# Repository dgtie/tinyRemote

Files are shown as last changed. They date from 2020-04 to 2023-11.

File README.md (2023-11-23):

# This project is obsolete
- please click [new tiny IR remote](https://github.com/dgtie/tinyRemote1/tree/main)

# tinyRemote
An infrared remote control with attiny414\
powered by 2 x AAA
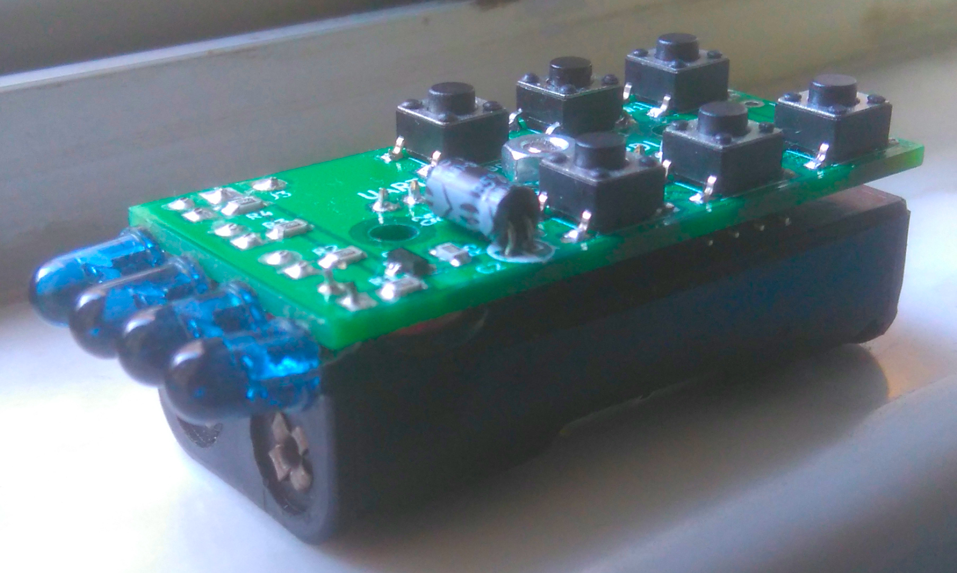
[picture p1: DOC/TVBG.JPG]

## Keys
```
              ____
vol- (99)    |o  o| ch-  (77)
vol+ (32)    |o  o| ch+  (31)
shift(power) |o  o| input(mute)
             |____|
              UUUU

Hit SHIFT and indicator will turn on. Then hit a button while indicator is on.

It shall work for SHARP, LG and TOSHIBA.
It shall also work for SONY, PHILIPS and SAMSUNG. (but not yet verified)
```
## Connecting to PC
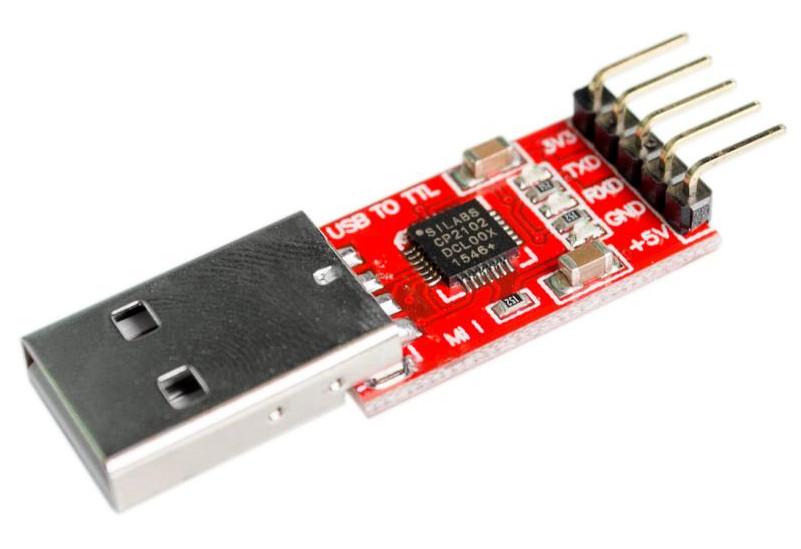
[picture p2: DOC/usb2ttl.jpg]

```
              ____
             |o  o| GND
      [UART] |o  o| 3V3
         GND |o  o| [UPDI]
         3V3 |____|
              UUUU
```
Connect tinyRemote to PC using a USB2TTL module via UPDI port or UART port. UPDI port is for programming attiny414. I am using [pyupdi](https://github.com/mraardvark/pyupdi).\
UART port is used for reading infrared code. There is an infrared transistor near the LED indicator. Point your remote controller CLOSE to it. To enter reading mode:
1. remove batteries
2. power up tinyRemote via UART port
3. IF SUCCESS, indicator will turn on. (It is a minor bug! Upon startup, Rx pin is checked. If it is high, enter reading mode.)

Baud rate is 115200. PC will receive BINARIES from tinyRemote representing the durations of marks and spaces. ZERO means break. The timing unit is 4.8 us.\
b2str.cpp is to convert the binaries to readable text string. The output will be durations in us.\
Decoding is done by PC (decode.cpp)\
pronto.cpp converts pronto hex to durations stream that to be decoded by decode.cpp
## Schematic
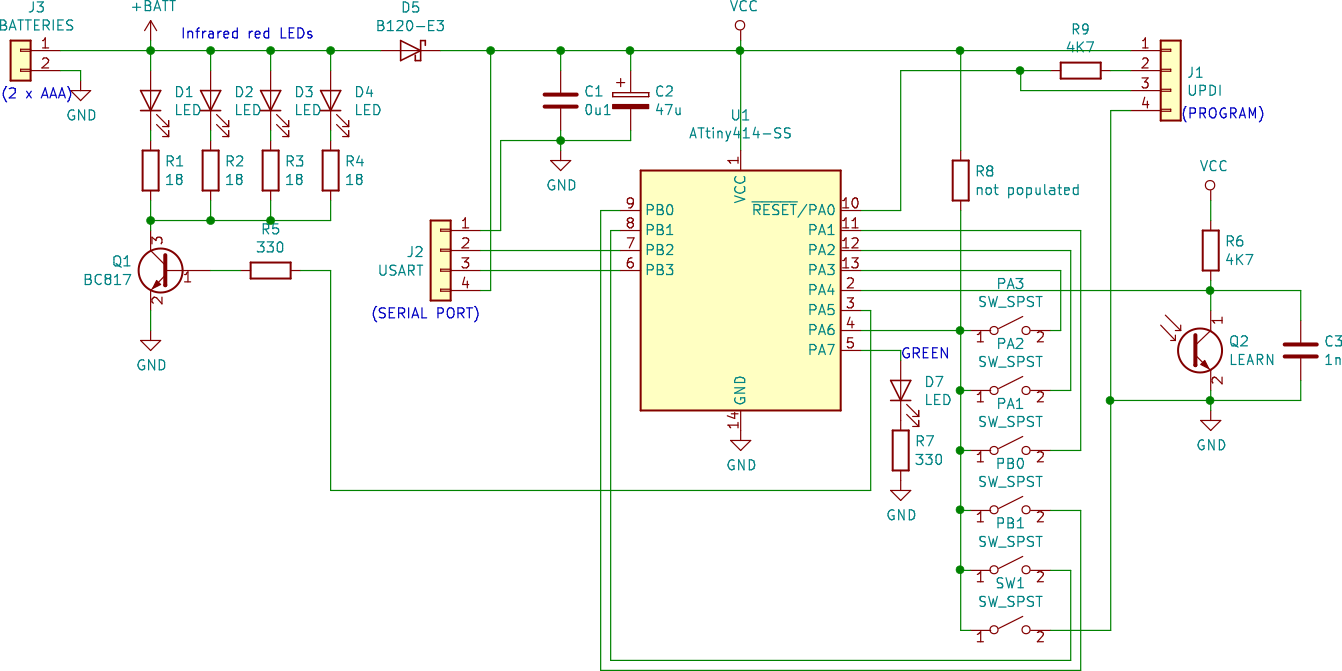
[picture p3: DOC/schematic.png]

https://user-images.githubusercontent.com/42087847/192790861-0ea7e591-97eb-486d-b9d1-ebd6bcc5e6a8.mp4

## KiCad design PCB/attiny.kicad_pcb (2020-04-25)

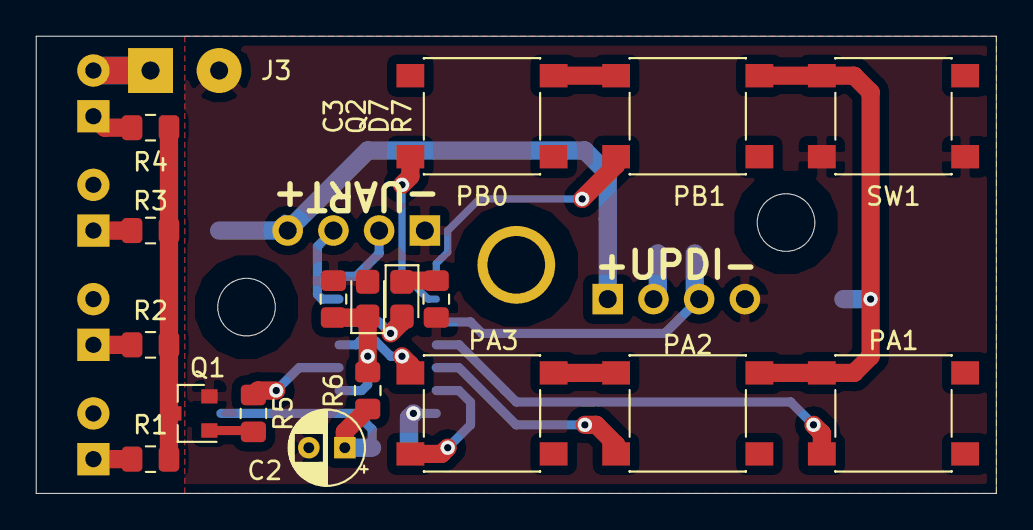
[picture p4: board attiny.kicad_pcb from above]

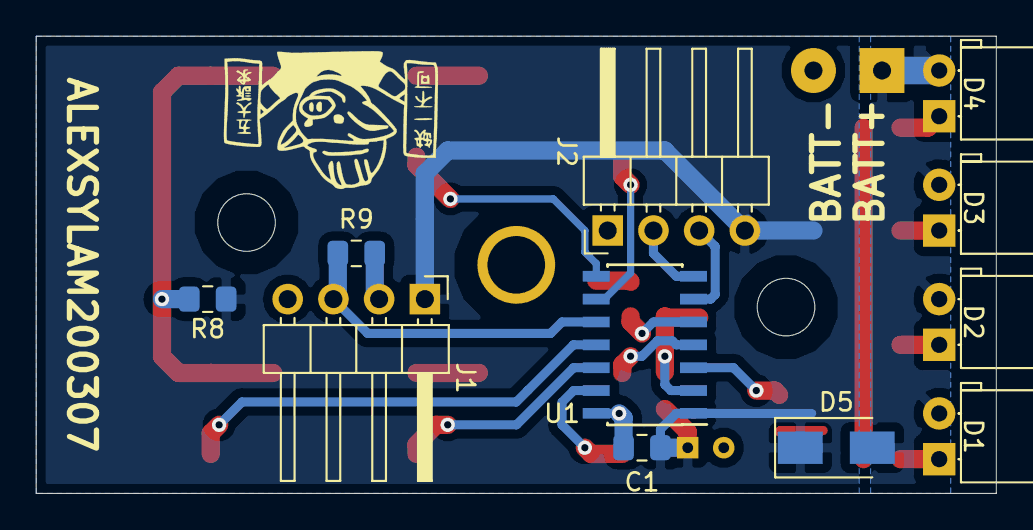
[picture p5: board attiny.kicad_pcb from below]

Board: 2 copper layers, 53.3 x 25.4 mm, 30 parts (11 on the bottom side), 23 nets.

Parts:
C1: 0u1; C_0805_2012Metric_Pad1.15x1.40mm_HandSolder
C2: 47u; CP_Radial_D4.0mm_P2.00mm
C3: 1n; C_0805_2012Metric_Pad1.15x1.40mm_HandSolder
D1, D2, D3, D4: LED; LED_D5.0mm_Horizontal_O1.27mm_Z3.0mm
D5: B120-E3; D_SMA
D7: LED; LED_0805_2012Metric_Castellated
J1, J2: Conn_01x04; PinHeader_1x04_P2.54mm_Horizontal
J3: Conn_01x02; SolderWirePad_1x02_P3.81mm_Drill1mm
PA1, PA2, PA3: SW_SPST; SW_SPST_PTS645
PB0, PB1: SW_SPST; SW_SPST_PTS645
Q1: BC817; SOT-23
Q2: Q_Photo_NPN; LED_0805_2012Metric_Castellated
R1, R2, R3, R4: 18; R_0805_2012Metric_Pad1.15x1.40mm_HandSolder
R5, R6, R8, R9: 4K7; R_0805_2012Metric_Pad1.15x1.40mm_HandSolder
R7: 330; R_0805_2012Metric_Pad1.15x1.40mm_HandSolder
SW1: SW_SPST; SW_SPST_PTS645
U1: ATtiny814-SS; SOIC-14_3.9x8.7mm_P1.27mm

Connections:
+BATT: D1.2, D2.2, D3.2, D4.2, D5.2, J3.1
GND: C1.2, C2.2, C3.2, J1.4, J2.1, J3.2, Q1.2, Q2.2, R7.2, SW1.2, U1.14
unnamed: C3.1, Q2.1, R6.2, U1.2
unnamed: D1.1, R1.1
unnamed: D2.1, R2.1
unnamed: D3.1, R3.1
unnamed: D4.1, R4.1
unnamed: D7.1, R7.1
unnamed: D7.2, U1.5
unnamed: J1.2, R9.1
unnamed: J1.3, R9.2, U1.10
unnamed: J2.2, U1.7
unnamed: J2.3, U1.6
unnamed: PA1.1, PA2.1, PA3.1, PB0.1, PB1.1, R8.2, SW1.1, U1.4
unnamed: PA1.2, U1.11
unnamed: PA2.2, U1.12
unnamed: PA3.2, U1.13
unnamed: PB0.2, U1.9
unnamed: PB1.2, U1.8
unnamed: Q1.1, R5.2
unnamed: Q1.3, R1.2, R2.2, R3.2, R4.2
unnamed: R5.1, U1.3
VCC: C1.1, C2.1, D5.1, J1.1, J2.4, R6.1, R8.1, U1.1

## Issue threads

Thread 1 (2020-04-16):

Instructions for compiling

alejomongua, 2020-04-16:
Hello.

I think this is a very interesting project. I am particularly interested in compiling and programing attiny414 on Linux.

I cloned your project, chaged the BIN variable in makefile for /usr/bin (which is where avr-* executables are located) but Im not able to compile.

I have avr-g++ versión 9.3.0 and I'm using manjaro

I have the following output when i run `make`

    /usr/bin/avr-g++ -mmcu=attiny414 -Os -o main.o -c main.cpp
    In file included from /usr/avr/include/avr/interrupt.h:38,
                     from main.cpp:1:
    /usr/avr/include/avr/io.h:581:6: warning: #warning "device type not defined" [-Wcpp]
      581 | #    warning "device type not defined"
          |      ^~~~~~~
    main.cpp: In function 'void init()':
    main.cpp:31:3: error: 'PORTA' was not declared in this scope; did you mean 'PORT0'?
       31 |   PORTA.DIRSET = PIN7_bm | PIN5_bm | PIN3_bm | PIN2_bm | PIN1_bm;
          |   ^~~~~
          |   PORT0
    main.cpp:31:18: error: 'PIN7_bm' was not declared in this scope; did you mean 'PIN7'?
       31 |   PORTA.DIRSET = PIN7_bm | PIN5_bm | PIN3_bm | PIN2_bm | PIN1_bm;
          |                  ^~~~~~~
          |                  PIN7
    main.cpp:31:28: error: 'PIN5_bm' was not declared in this scope; did you mean 'PIN5'?
       31 |   PORTA.DIRSET = PIN7_bm | PIN5_bm | PIN3_bm | PIN2_bm | PIN1_bm;
          |                            ^~~~~~~
          |                            PIN5
    main.cpp:31:38: error: 'PIN3_bm' was not declared in this scope; did you mean 'PIN3'?
       31 |   PORTA.DIRSET = PIN7_bm | PIN5_bm | PIN3_bm | PIN2_bm | PIN1_bm;
          |                                      ^~~~~~~
          |                                      PIN3
    main.cpp:31:48: error: 'PIN2_bm' was not declared in this scope; did you mean 'PIN2'?
       31 |   PORTA.DIRSET = PIN7_bm | PIN5_bm | PIN3_bm | PIN2_bm | PIN1_bm;
          |                                                ^~~~~~~
          |                                                PIN2
    main.cpp:31:58: error: 'PIN1_bm' was not declared in this scope; did you mean 'PIN1'?
       31 |   PORTA.DIRSET = PIN7_bm | PIN5_bm | PIN3_bm | PIN2_bm | PIN1_bm;
          |                                                          ^~~~~~~
          |                                                          PIN1
    main.cpp:32:3: error: 'PORTB' was not declared in this scope; did you mean 'PORT0'?
       32 |   PORTB.DIRSET = PIN2_bm | PIN1_bm | PIN0_bm;
          |   ^~~~~
          |   PORT0
    main.cpp:32:38: error: 'PIN0_bm' was not declared in this scope; did you mean 'PIN0'?
       32 |   PORTB.DIRSET = PIN2_bm | PIN1_bm | PIN0_bm;
          |                                      ^~~~~~~
          |                                      PIN0
    main.cpp:33:3: error: 'TCB0' was not declared in this scope
       33 |   TCB0.CTRLB = TCB_CCMPEN_bm | TCB_CNTMODE_PWM8_gc; // carrier
          |   ^~~~
    main.cpp:33:16: error: 'TCB_CCMPEN_bm' was not declared in this scope
       33 |   TCB0.CTRLB = TCB_CCMPEN_bm | TCB_CNTMODE_PWM8_gc; // carrier
          |                ^~~~~~~~~~~~~
    main.cpp:33:32: error: 'TCB_CNTMODE_PWM8_gc' was not declared in this scope
       33 |   TCB0.CTRLB = TCB_CCMPEN_bm | TCB_CNTMODE_PWM8_gc; // carrier
          |                                ^~~~~~~~~~~~~~~~~~~
    main.cpp:34:3: error: 'TCA0' was not declared in this scope
       34 |   TCA0.SINGLE.INTCTRL = TCA_SINGLE_OVF_bm;
          |   ^~~~
    main.cpp:34:25: error: 'TCA_SINGLE_OVF_bm' was not declared in this scope
       34 |   TCA0.SINGLE.INTCTRL = TCA_SINGLE_OVF_bm;
          |                         ^~~~~~~~~~~~~~~~~
    main.cpp: In lambda function:
    main.cpp:46:7: error: 'USART0' was not declared in this scope
       46 |   if (USART0.CTRLB) usart0(count);
          |       ^~~~~~
    main.cpp:49:5: error: 'TCA0' was not declared in this scope
       49 |     TCA0.SINGLE.CTRLA = TCA_SINGLE_CLKSEL_DIV1_gc | TCA_SINGLE_ENABLE_bm;
          |     ^~~~
    main.cpp:49:25: error: 'TCA_SINGLE_CLKSEL_DIV1_gc' was not declared in this scope
       49 |     TCA0.SINGLE.CTRLA = TCA_SINGLE_CLKSEL_DIV1_gc | TCA_SINGLE_ENABLE_bm;
          |                         ^~~~~~~~~~~~~~~~~~~~~~~~~
    main.cpp:49:53: error: 'TCA_SINGLE_ENABLE_bm' was not declared in this scope
       49 |     TCA0.SINGLE.CTRLA = TCA_SINGLE_CLKSEL_DIV1_gc | TCA_SINGLE_ENABLE_bm;
          |                                                     ^~~~~~~~~~~~~~~~~~~~
    main.cpp: In function 'void key(char)':
    main.cpp:57:3: error: 'SLPCTRL' was not declared in this scope
       57 |   SLPCTRL.CTRLA = 0;
          |   ^~~~~~~
    main.cpp: In function 'int main()':
    main.cpp:61:3: error: 'TCA0' was not declared in this scope
       61 |   TCA0.SINGLE.CTRLA = TCA_SINGLE_CLKSEL_DIV1024_gc | TCA_SINGLE_ENABLE_bm;
          |   ^~~~
    main.cpp:61:23: error: 'TCA_SINGLE_CLKSEL_DIV1024_gc' was not declared in this scope
       61 |   TCA0.SINGLE.CTRLA = TCA_SINGLE_CLKSEL_DIV1024_gc | TCA_SINGLE_ENABLE_bm;
          |                       ^~~~~~~~~~~~~~~~~~~~~~~~~~~~
    main.cpp:61:54: error: 'TCA_SINGLE_ENABLE_bm' was not declared in this scope
       61 |   TCA0.SINGLE.CTRLA = TCA_SINGLE_CLKSEL_DIV1024_gc | TCA_SINGLE_ENABLE_bm;
          |                                                      ^~~~~~~~~~~~~~~~~~~~
    main.cpp:64:26: error: 'TCA_SINGLE_OVF_bm' was not declared in this scope
       64 |   TCA0.SINGLE.INTFLAGS = TCA_SINGLE_OVF_bm;
          |                          ^~~~~~~~~~~~~~~~~
    main.cpp:66:7: error: 'PORTB' was not declared in this scope; did you mean 'PORT0'?
       66 |   if (PORTB.IN & PIN3_bm) learn(); // learn() won't return
          |       ^~~~~
          |       PORT0
    main.cpp:66:18: error: 'PIN3_bm' was not declared in this scope; did you mean 'PIN3'?
       66 |   if (PORTB.IN & PIN3_bm) learn(); // learn() won't return
          |                  ^~~~~~~
          |                  PIN3
    main.cpp:67:3: error: 'PORTA' was not declared in this scope; did you mean 'PORT0'?
       67 |   PORTA.PIN6CTRL = PORT_PULLUPEN_bm | PORT_ISC_FALLING_gc;
          |   ^~~~~
          |   PORT0
    main.cpp:67:20: error: 'PORT_PULLUPEN_bm' was not declared in this scope
       67 |   PORTA.PIN6CTRL = PORT_PULLUPEN_bm | PORT_ISC_FALLING_gc;
          |                    ^~~~~~~~~~~~~~~~
    main.cpp:67:39: error: 'PORT_ISC_FALLING_gc' was not declared in this scope
       67 |   PORTA.PIN6CTRL = PORT_PULLUPEN_bm | PORT_ISC_FALLING_gc;
          |                                       ^~~~~~~~~~~~~~~~~~~
    main.cpp:68:11: error: 'SLPCTRL' was not declared in this scope
       68 |   while ((SLPCTRL.CTRLA = SLPCTRL_SMODE_PDOWN_gc | SLPCTRL_SEN_bm)) {
          |           ^~~~~~~
    main.cpp:68:27: error: 'SLPCTRL_SMODE_PDOWN_gc' was not declared in this scope
       68 |   while ((SLPCTRL.CTRLA = SLPCTRL_SMODE_PDOWN_gc | SLPCTRL_SEN_bm)) {
          |                           ^~~~~~~~~~~~~~~~~~~~~~
    main.cpp:68:52: error: 'SLPCTRL_SEN_bm' was not declared in this scope
       68 |   while ((SLPCTRL.CTRLA = SLPCTRL_SMODE_PDOWN_gc | SLPCTRL_SEN_bm)) {
          |                                                    ^~~~~~~~~~~~~~
    In file included from main.cpp:1:
    main.cpp: In function 'void PORTA_PORT_vect()':
    main.cpp:99:5: warning: 'PORTA_PORT_vect' appears to be a misspelled 'signal' handler, missing '__vector' prefix [-Wmisspelled-isr]
       99 | ISR(PORTA_PORT_vect) {
          |     ^~~~~~~~~~~~~~~
    main.cpp:100:11: error: 'TCA0' was not declared in this scope
      100 |   count = TCA0.SINGLE.CNT;
          |           ^~~~
    main.cpp:101:7: error: 'USART0' was not declared in this scope
      101 |   if (USART0.CTRLB) TCA0.SINGLE.CNT = 0;
          |       ^~~~~~
    main.cpp:102:3: error: 'PORTA' was not declared in this scope; did you mean 'PORT0'?
      102 |   PORTA.INTFLAGS = PIN4_bm;
          |   ^~~~~
          |   PORT0
    main.cpp:102:20: error: 'PIN4_bm' was not declared in this scope; did you mean 'PIN4'?
      102 |   PORTA.INTFLAGS = PIN4_bm;
          |                    ^~~~~~~
          |                    PIN4
    main.cpp:103:25: error: 'PORT_PULLUPEN_bm' was not declared in this scope
      103 |   if (PORTA.PIN6CTRL == PORT_PULLUPEN_bm | PORT_ISC_FALLING_gc) {
          |                         ^~~~~~~~~~~~~~~~
    main.cpp:103:44: error: 'PORT_ISC_FALLING_gc' was not declared in this scope
      103 |   if (PORTA.PIN6CTRL == PORT_PULLUPEN_bm | PORT_ISC_FALLING_gc) {
          |                                            ^~~~~~~~~~~~~~~~~~~
    main.cpp:104:41: error: 'PORT_ISC_INTDISABLE_gc' was not declared in this scope
      104 |     PORTA.PIN6CTRL = PORT_PULLUPEN_bm | PORT_ISC_INTDISABLE_gc;
          |                                         ^~~~~~~~~~~~~~~~~~~~~~
    main.cpp:105:5: error: 'SLPCTRL' was not declared in this scope
      105 |     SLPCTRL.CTRLA = 0;
          |     ^~~~~~~
    In file included from main.cpp:1:
    main.cpp: In function 'void TCA0_OVF_vect()':
    main.cpp:110:5: warning: 'TCA0_OVF_vect' appears to be a misspelled 'signal' handler, missing '__vector' prefix [-Wmisspelled-isr]
      110 | ISR(TCA0_OVF_vect) {
          |     ^~~~~~~~~~~~~
    main.cpp:111:3: error: 'TCA0' was not declared in this scope
      111 |   TCA0.SINGLE.INTFLAGS = TCA_SINGLE_OVF_bm;
          |   ^~~~
    main.cpp:111:26: error: 'TCA_SINGLE_OVF_bm' was not declared in this scope
      111 |   TCA0.SINGLE.INTFLAGS = TCA_SINGLE_OVF_bm;
          |                          ^~~~~~~~~~~~~~~~~
    make: *** [Makefile:35: main.o] Error 1

Steps to reproduce the problem:

1. clone the repo
2. cd to repo folder
3. make clean
4. make

dgtie, 2020-04-16:
I learned programming attiny414  from the following site:
https://git.omegav.no/avrkurs/attinykurs

Just uploaded the required additional files for the compiler

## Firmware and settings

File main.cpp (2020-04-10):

#include <avr/interrupt.h>
#include "lamos.h"

/*
  PA4: IR Transistor
  PA5: IR LED (TCB0/WO)
  PA6: Button Sense
  PA7: LED
  PB2, PB3: USART0 (TxD, RxD)
  PB0, PB1, PA1~3, GND: Button

  Default CLK_PER = 20 MHz / 6 = 3.333 MHz
  Only Px2 and Px6 are asynchronous
  Other PIN can't wake at RISING/FALLING

  to activate USART: power up with USART connected to PC
*/

namespace user {
void power(), mute(), vol_up(), vol_down(), ch_up(), ch_down();
void input(), k31(), k32(), k77(), k99();
}

extern char delay;
extern Service tca0;
void usart0(int), learn();

unsigned int shift;

void __attribute__((naked, section(".init3"))) init(void) {
  PORTA.DIRSET = PIN7_bm | PIN5_bm | PIN3_bm | PIN2_bm | PIN1_bm;
  PORTB.DIRSET = PIN2_bm | PIN1_bm | PIN0_bm;
  TCB0.CTRLB = TCB_CCMPEN_bm | TCB_CNTMODE_PWM8_gc;	// carrier
  TCA0.SINGLE.INTCTRL = TCA_SINGLE_OVF_bm;
}

namespace
{

char ukey;
volatile char ikey;

int count;

Service porta([](){
  if (USART0.CTRLB) usart0(count);
  else {
    delay = 50;
    TCA0.SINGLE.CTRLA = TCA_SINGLE_CLKSEL_DIV1_gc | TCA_SINGLE_ENABLE_bm;
  }
});

} // anonymous

void key(char c) {
  ikey = ikey == c ? (c | 0x80) : c;
  SLPCTRL.CTRLA = 0;
}

int main(void) {
  TCA0.SINGLE.CTRLA = TCA_SINGLE_CLKSEL_DIV1024_gc | TCA_SINGLE_ENABLE_bm;
  TCA0.SINGLE.PER = 1847;	// key bounce delay
  while (!TCA0.SINGLE.INTFLAGS);
  TCA0.SINGLE.INTFLAGS = TCA_SINGLE_OVF_bm;
  sei();
  if (PORTB.IN & PIN3_bm) learn();	// learn() won't return
  PORTA.PIN6CTRL = PORT_PULLUPEN_bm | PORT_ISC_FALLING_gc;
  while ((SLPCTRL.CTRLA = SLPCTRL_SMODE_PDOWN_gc | SLPCTRL_SEN_bm)) {
    if (ukey != ikey) {
      ukey = ikey;
      using namespace user;
      if (shift) {
        shift = 0;
        switch (ukey & 7) {	// remove toggle bit
        case 0: k99(); break;		// ^^^^
        case 1: k77(); break;		// |  |
        case 2: k31(); break;		// 3  4
        case 3: mute(); break;		// 2  5
        case 4: power(); break;		// 1  0
        case 5: k32(); break;		// ----
        default:;
        }
      } else {
        switch (ukey & 7) {	// remove toggle bit
        case 0: vol_down(); break;	// ^^^^
        case 1: ch_down(); break;	// |  |
        case 2: ch_up(); break;		// 3  4
        case 3: input(); break;		// 2  5
        case 4: shift = 10000; break;	// 1  0
        case 5: vol_up(); break;	// ----
        default:;
        }
      }
    }
    if (!TCA0.SINGLE.CTRLA) asm("sleep");
  }
}

ISR(PORTA_PORT_vect) {
  count = TCA0.SINGLE.CNT;
  if (USART0.CTRLB) TCA0.SINGLE.CNT = 0;
  PORTA.INTFLAGS = PIN4_bm;
  if (PORTA.PIN6CTRL == PORT_PULLUPEN_bm | PORT_ISC_FALLING_gc) {
    PORTA.PIN6CTRL = PORT_PULLUPEN_bm | PORT_ISC_INTDISABLE_gc; 
    SLPCTRL.CTRLA = 0;
  }
  _append(porta);
}

ISR(TCA0_OVF_vect) {
  TCA0.SINGLE.INTFLAGS = TCA_SINGLE_OVF_bm;
  _append(tca0);
}

/*
stty -F /dev/ttyUSB0 115200 raw
cat /dev/ttyUSB0
*/

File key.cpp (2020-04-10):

#include <avr/io.h>
#include "lamos.h"

extern unsigned int shift;

char delay;
void usart0();
bool getDuty();
void key(char);

namespace
{

bool pa6(char) { return PORTA.IN & PIN6_bm; }

void __attribute__((optimize("O0"))) scan() {
  PORTA.OUTSET = PIN3_bm | PIN2_bm | PIN1_bm;
  PORTB.OUTSET = PIN1_bm | PIN0_bm;
  if (!pa6(0)) key(0);
  else if (!pa6(PORTA.OUTCLR = PIN3_bm)) key(3);
  else if (!pa6(PORTA.OUTCLR = PIN2_bm)) key(2);
  else if (!pa6(PORTA.OUTCLR = PIN1_bm)) key(1);
  else if (!pa6(PORTB.OUTCLR = PIN1_bm)) key(5);
  else if (!pa6(PORTB.OUTCLR = PIN0_bm)) key(4);
  PORTA.OUTCLR = PIN3_bm | PIN2_bm | PIN1_bm;
  PORTB.OUTCLR = PIN1_bm | PIN0_bm;
  PORTA.INTFLAGS = PIN6_bm;
  PORTA.PIN6CTRL = PORT_PULLUPEN_bm | PORT_ISC_FALLING_gc;
}

} //anonymous

Service tca0([](){
  if (USART0.CTRLB) usart0();
  else {
    if (getDuty()) {
      TCB0.CCMPH = 30;
      PORTA.OUTSET = PIN7_bm;
    } else {
      TCB0.CCMPH = 0;
      if (!shift) PORTA.OUTCLR = PIN7_bm;
    }
    if (delay) { if (!--delay) scan(); }
    else {
      if (shift) { PORTA.OUTSET = PIN7_bm; shift--; }
      else {
        if (!TCB0.CTRLA) {
          TCA0.SINGLE.CTRLA = 0;
          PORTA.OUTCLR = PIN7_bm;
        }
      }
    }
  }
});
